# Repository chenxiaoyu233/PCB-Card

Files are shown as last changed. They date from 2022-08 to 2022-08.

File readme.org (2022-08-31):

I always want to build some customized devices for myself, in which I have to implement both the hardware and the software.
I am quite familiar with softare development but only with little experience for the hardware development.

To implement the hardware, the most important part seems to be the design of printed circuit board (PCB).
And this project aims at gaining such kind of experience.

* The Card-V1 Project
** Startup
    First, I install the KiCad on my mac and I learn how to use it on bilibili.
    At the beginning, I randomly choose a MCU on [[https://list.szlcsc.com/][立创商城]], which is named as STM32L073RBT6 (about ¥50).
    Then I try to design the PCB according to this chip.

** Design the Schematic
    The most frustrated part in this step is to answer the question about how to driven the STM32L073RBT6 chip.
    That is, I want to know the "smallest" working requirement of this chip.
    Besides, I also need to figure out how to achieve these requirements on the PCB.
    Luckly, after a very long time, I find an article about how to achieve this ([[./doc/an4467-getting-started-with-stm32l0xx-hardware-development-stmicroelectronics.pdf][STM32L0xx-Hardware]]).

    Another question is to write my program into the chip.
    I find out that STM32L073RBT6 support USB DFU protocol in [[./doc/STM32-BOOT.pdf][STM32-BOOT]] (section 37.1).
    And I plan to download my program by a USB type-C port.
    Now, the question is, how to connect the USB prot to STM32L073RBT6 ?
    I find the answer in [[./doc/STM32-USB-Hardware.pdf][STM32-USB-Hardware]] (section 3.1.2).
    The USB port also handles the power supply.

    For future concern, I also add a circuit for a 1.54 inch e-paper screen ([[https://www.waveshare.net/shop/1.54inch-e-Paper-B.htm][e-paper-screen]]).
    The final result is like
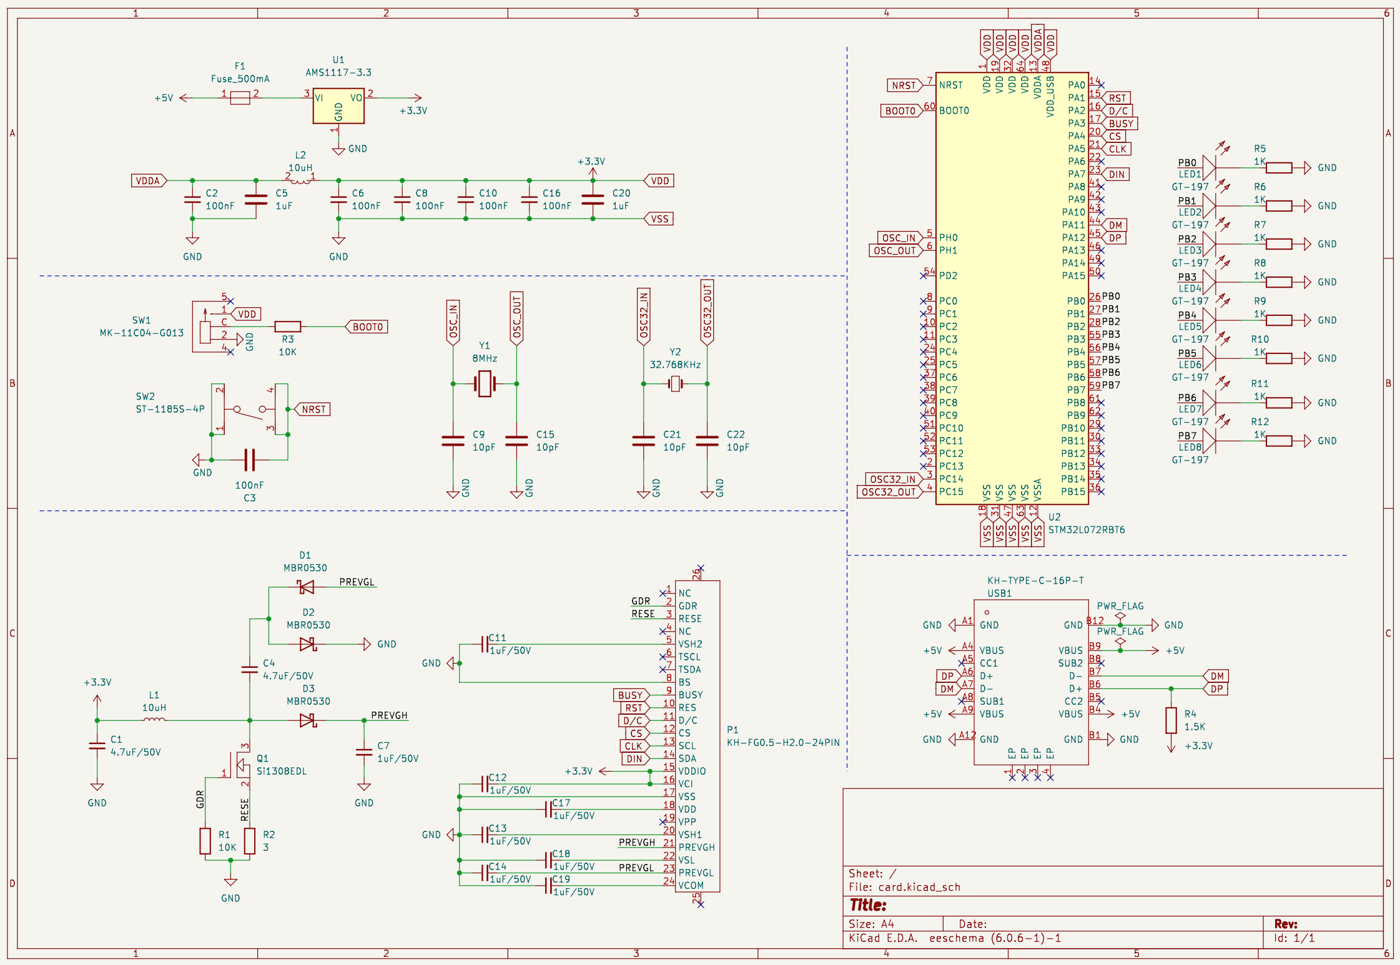
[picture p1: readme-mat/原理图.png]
    

** Design the PCB layout
    This step is quite simple because my pcb only runs at low speed.
    The final result is
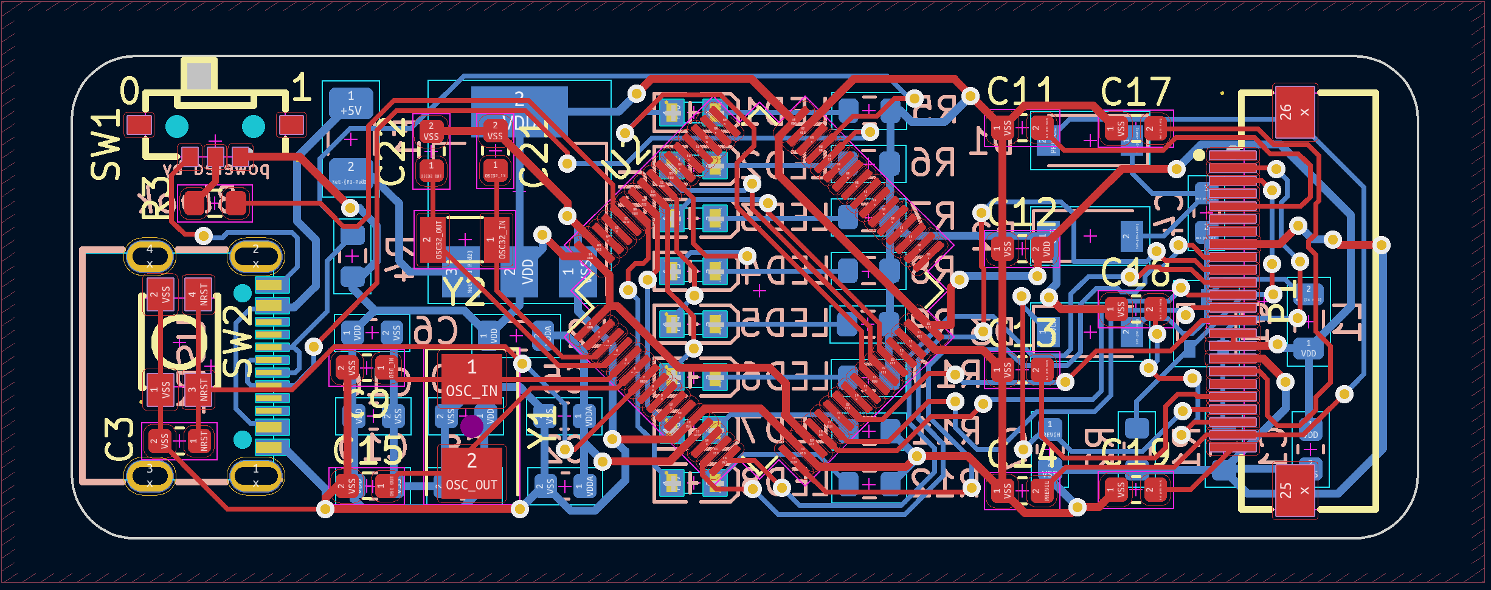
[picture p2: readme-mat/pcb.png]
    

** Order and Assemble
    I bought all the materials on [[https://list.szlcsc.com/][立创商城]] (about ¥60/suit) and order the PCB on [[https://www.jlc.com][嘉立创]] (about ¥30 for 5 PCBs).
    I assemble and weld these materials by using a heat gun.
    Here is the results.
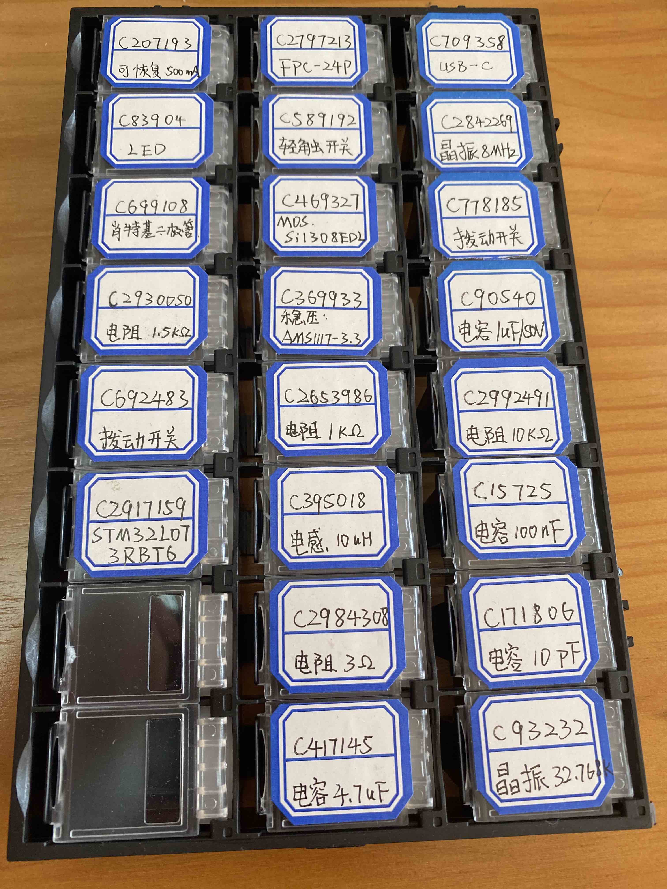
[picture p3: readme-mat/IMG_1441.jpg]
    
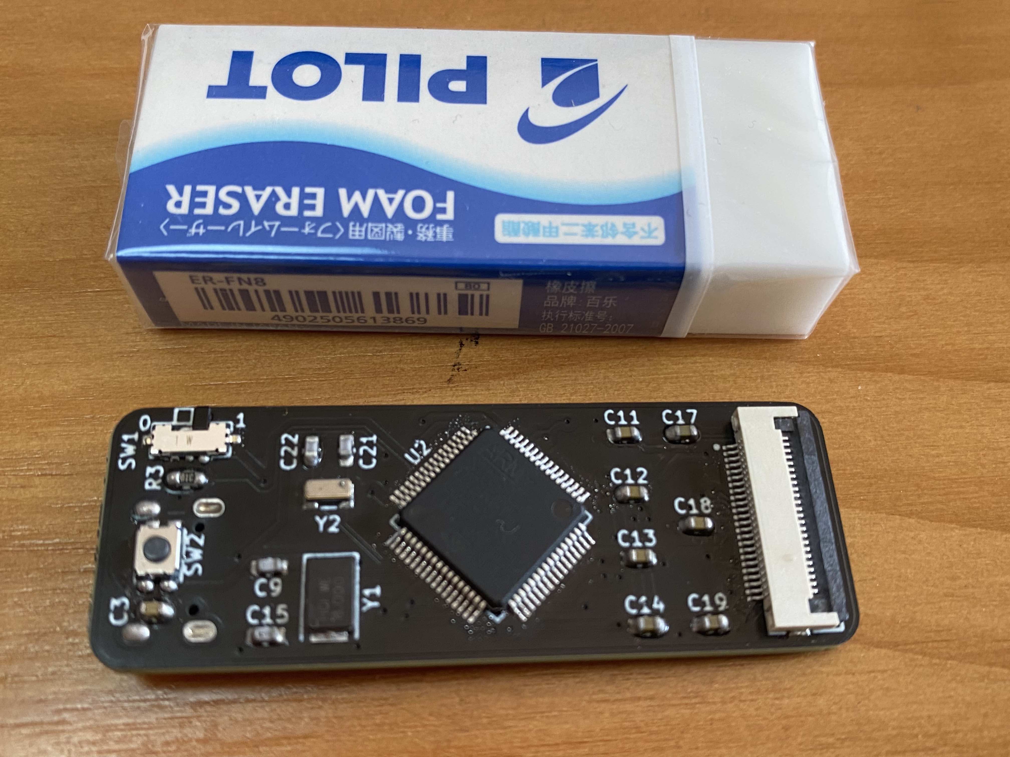
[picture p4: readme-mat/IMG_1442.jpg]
    
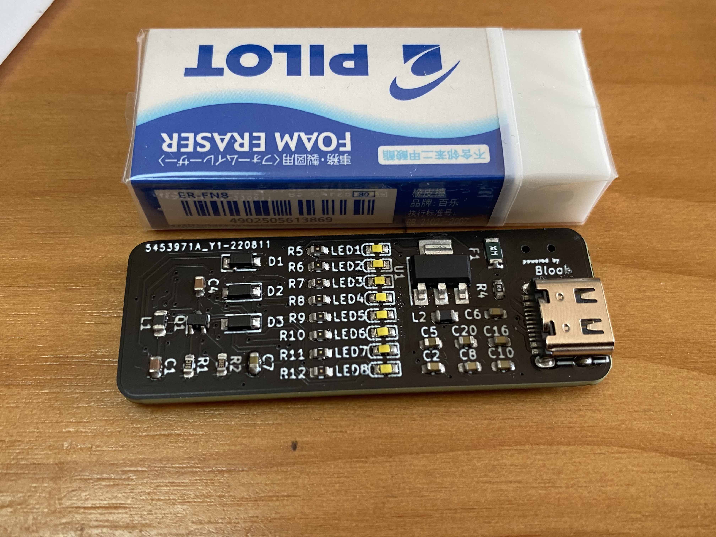
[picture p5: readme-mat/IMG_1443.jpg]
    

** Write Software and Blink the LED
    The document provided by ST ([[./doc/STM32L0x3-man.pdf][STM32L0x3-Manual]]) is very frustrated to read.
    It is so long and makes you confused about where to start.
    The crucial information for us is the boot mechanism of the chip.

    The chip has a RAM at =0x20002000= - =0x20004FFF= and a read-only flash memory at =0x08000000= - =0x0802FFFF=.
    When BOOT0 pin is set to 1, the chip runs a hard coded bootloader specified in [[./doc/STM32-BOOT.pdf][STM32-BOOT]] (section 37.1).
    This bootloader supports USB DFU protocol, which allows us to download our executables to the chip by the tool =dfu-util=.
    Our program need to be written in the beginning of the flash memory at =0x08000000=.

    When BOOT0 pin is set to 0, the chip initialized as follows:
    1. set the 32bit at =0x08000000= - =0x08000003= to register =SP=, which always point to the top of the stack (the stack grow towards 0).
       Typically, these 32bit should be set as =0x20004FFF= as the bottom of the RAM.
    2. set the 32bit at =0x08000004= - =0x08000007= to register =PC=, which is the program counter.

    This indicates us about how to initialize in our program.

    Now, since we connect the LEDs to the GPIOB ports of the chip, we only need to write 1 to GPIOB port to enlighten the LEDs.
    To do this, we need first enable the GPIOB ports at =RCC_IOPENR= register ([[./doc/STM32L0x3-man.pdf][STM32L0x3-Manual]], section 7.3.12).
    (I miss this step at first, and it tooks me a lot of time to figure out what happens).
    Then, we need to initialize the GPIOB ports by =GPIOB_MODER=, =GPIOB_OTYPER=, =GPIOB_OSPEEDR=, =GPIOB_PUPDR=, =GPIOB_ODR= registers ([[./doc/STM32L0x3-man.pdf][STM32L0x3-Manual]], section 9.4).
    These registers could be accessed using certain memory address.

    All the code could find at [[./code][code]].

** Debug
    Since I only use USB port to download the program, my PCB lacks debug infrastructure like SWD and ST-Link.
    So, I cannot do any on-board debugging, which makes it really hard to find out whats going wrong.

    Luckily, I could use qemu to simulate the STM32 and run my program on it first.
    Though the model is not exactly the same, it still helps me a lot.
    The material on [[./doc/STM32L0x3-man.pdf][STM32L0x3-Manual]] for the boot behavior is very ambiguous, you have to do some experiment to figure out what happens.

** Final Results
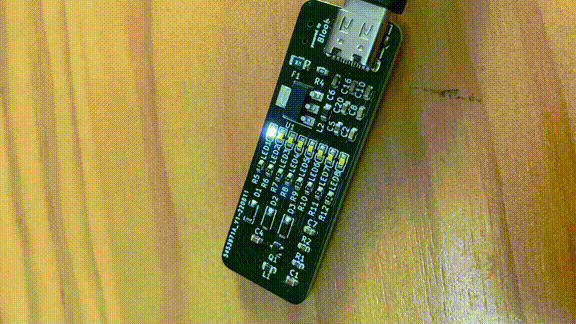
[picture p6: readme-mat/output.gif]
    
    
* The Card-V2 Project
  Based on the same hardware, the "card" could be use to drive an e-paper dispaly:  [[https://www.waveshare.net/shop/1.54inch-e-Paper.htm][wareshare 1.54inch e-paper]].
  During the development, I find that I use the wrong type of FPC connector, the original one is replaced by [[https://item.szlcsc.com/3194063.html][0425-A-A04-002 (C2911807)]].
  Moreover, the welding is really difficult and it tooks me tons of time to debug.

** Final Results
    Most code is generated by a tool called =STM32CubeMX=.
    The code is placed in [[./USBLib]] and could be build using =make=.
    Before using =make=, one should find an image of 200x200 and run =image-bin.py= in the folder =EPD= to convert it into a c header.

    The result is like:
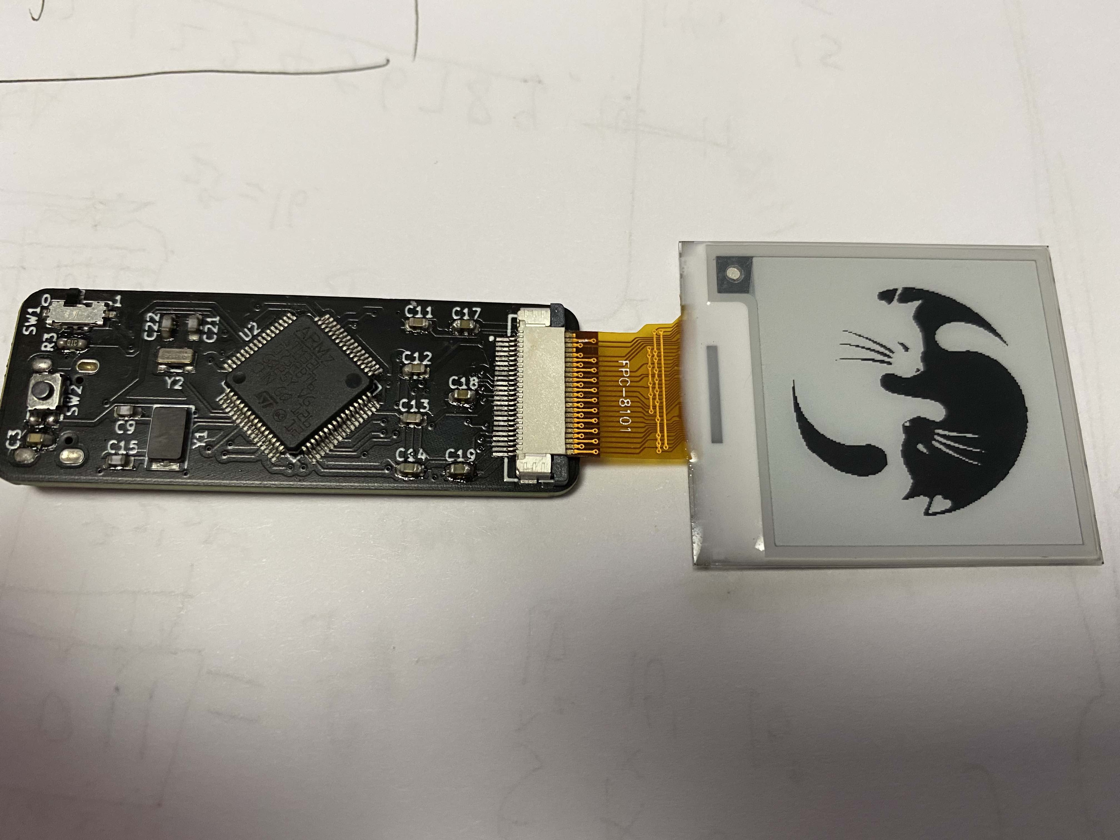
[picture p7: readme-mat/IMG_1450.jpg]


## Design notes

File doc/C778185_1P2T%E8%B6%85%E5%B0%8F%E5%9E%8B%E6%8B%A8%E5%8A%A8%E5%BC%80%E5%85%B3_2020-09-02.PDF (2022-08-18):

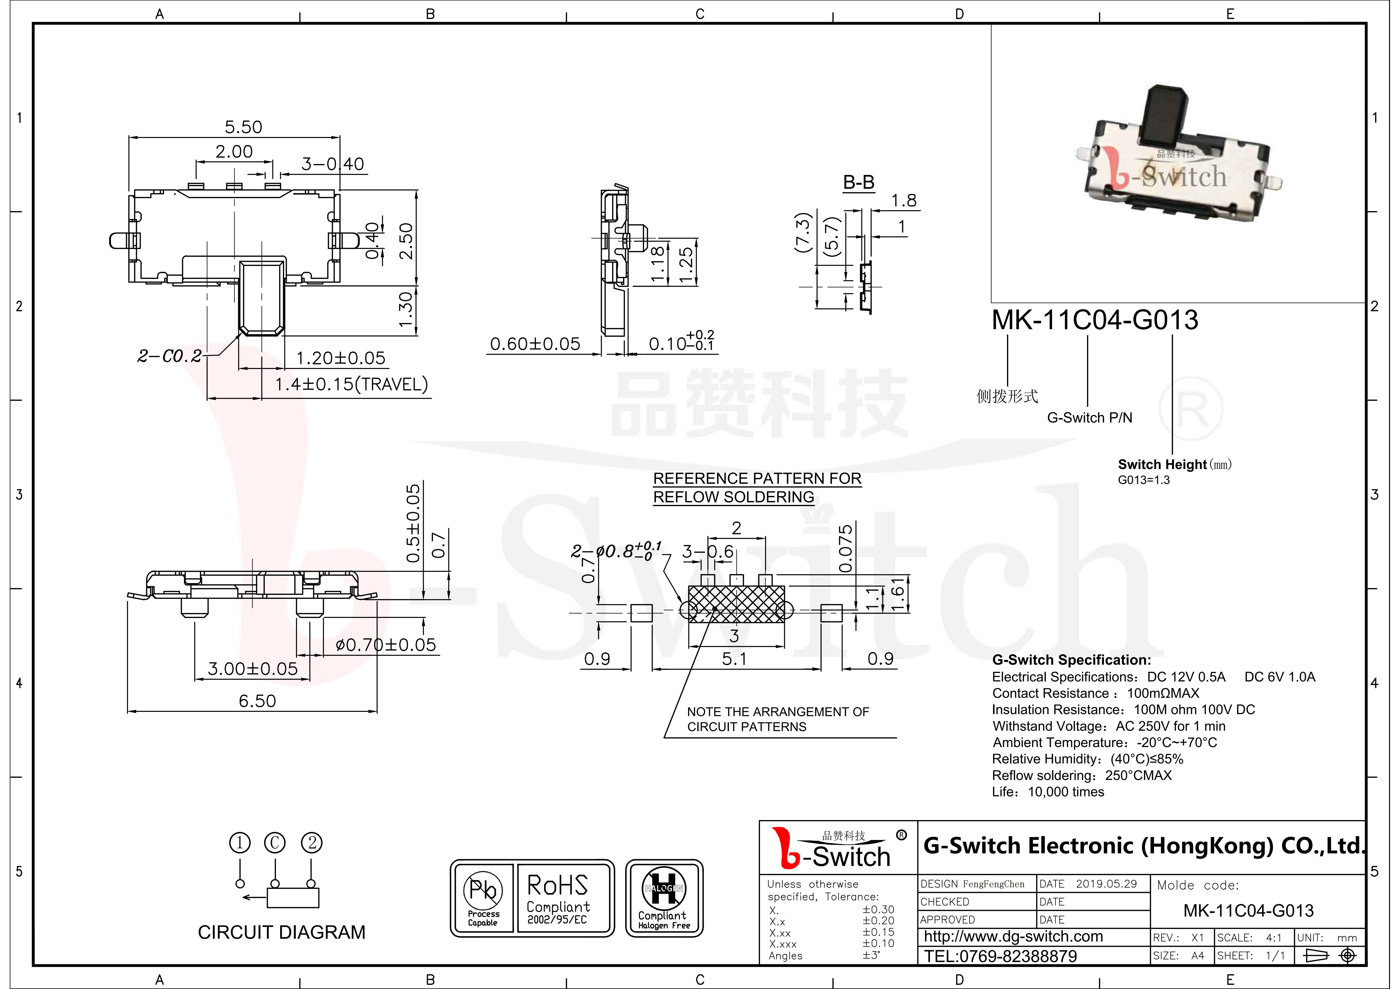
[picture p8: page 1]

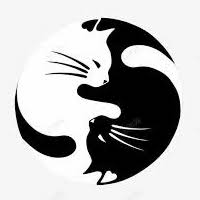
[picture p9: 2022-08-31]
USBLib/EPD/images.jpeg

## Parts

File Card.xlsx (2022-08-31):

Card 项目物料BOM清单
序号 | 名称 | 型号/规格 | 封装 | 用量 | 品牌 | 商品编号
1 | USB连接器 | KH-TYPE-C-16P-T | USB-C-SMD_KH-TYPE-C-16P | 1 | kinghelm | C709358
2 | 贴片无源晶振 | XC53G2-8.000-F12NJHP | SMD5032-2P | 1 | HCI | C2842269
3 | 1P2T超小型拨动开关 | MK-11C04-G013 | SW-SMD_MK-11C04-G013 | 1 | G-Switch | C778185
4 | 贴片电容 | 1uF ±10% 50V | 0603 | 8 | FH | C90540
5 | 贴片电阻 | 10kΩ ±0.1% | 0603 | 2 | Viking | C2992491
6 | 贴片电容 | 100nF ±10% 100V | 0603 | 6 | SAMSUNG | C15725
7 | 贴片电容 | 10pF ±0.5pF 50V | 0603 | 4 | TDK | C171806
8 | 贴片无源晶振 | 32.768KHz 12.5PF 20ppm | SMD3215-2P | 1 | KDS | C93232
9 | MCU | STM32L073RBT6 | LQFP-64 | 1 | ST | C915968
10 | FFC/FPC连接器 | 0425-A-A04-002 | FPC-SMD_KH-FG0.5-H2.0-24PIN | 1 | HDGC | C2911807
11 | 轻触开关 | ST-1185S-4P | SW-SMD_ST-1185S-4P | 1 | RISHENG | C589192
12 | 场效应管 | SI1308EDL-T1-GE3 | SOT-323 | 1 | VISHAY | C469327
13 | 线性稳压器 | AMS1117-3.3 | SOT-223 | 1 | KEXIN | C369933
14 | 贴片电容 | 1uF ±10% 50V | 0603 | 2 | FH | C90540
15 | 贴片电阻 | 1kΩ ±1% 250mW | 0603 | 8 | ROHM | C2653986
16 | 贴片电感 | 10uH ±10% | 0805 | 2 | FH | C395018
17 | 贴片电阻 | 3Ω ±0.1% 62.5mW | 0603 | 1 | Viking | C2984308
18 | 贴片电容 | 4.7uF ±10% | 0603 | 2 | muRata | C417145
19 | 可恢复保险丝 | 500mA | 1206 | 1 | Littelfuse | C207193
20 | 发光二极管 | GT-197 | 0603 | 8 | EVERLIGHT | C83904
21 | 肖特基二极管 | MBR0530 | SOD-123 | 3 | YANGJIE | C699108
22 | 贴片电阻 | 1.5kΩ ±1% 100mW | 0603 | 1 | FOJAN | C2930050
请将需要匹配的BOM放在第一个工作表即sheet1

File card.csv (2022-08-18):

ID | 指示符 | 软件包 | 数量 | 名称 | 供应商和参考
1 | USB1 | USB-C-SMD_KH-TYPE-C-16P | 1 | KH-TYPE-C-16P-T
2 | Y1 | Crystal_SMD_5032-2Pin_5.0x3.2mm | 1 | 8MHz
3 | SW1 | SW-SMD_MK-11C04-G013 | 1 | MK-11C04-G013
4 | C13,C11,C17,C19,C18,C14,C12,C7 | C_0603_1608Metric | 8 | 1uF/50V
5 | R3,R1 | R_0603_1608Metric | 2 | 10K
6 | C3,C6,C2,C10,C8,C16 | C_0603_1608Metric | 6 | 100nF
7 | C22,C15,C9,C21 | C_0603_1608Metric | 4 | 10pF
8 | Y2 | Crystal_SMD_3215-2Pin_3.2x1.5mm | 1 | 32.768KHz
9 | U2 | LQFP-64_10x10mm_P0.5mm | 1 | STM32L072RBT6
10 | P1 | FPC-SMD_KH-FG0.5-H2.0-24PIN | 1 | KH-FG0.5-H2.0-24PIN
11 | SW2 | SW-SMD_ST-1185S-4P | 1 | ST-1185S-4P
12 | Q1 | SOT-323_SC-70 | 1 | Si1308EDL
13 | U1 | SOT-223-3_TabPin2 | 1 | AMS1117-3.3
14 | C5,C20 | C_0603_1608Metric | 2 | 1uF
15 | R11,R5,R8,R10,R6,R9,R12,R7 | R_0603_1608Metric | 8 | 1K
16 | L1,L2 | L_0805_2012Metric | 2 | 10uH
17 | R2 | R_0603_1608Metric | 1 | 3
18 | C1,C4 | C_0603_1608Metric | 2 | 4.7uF/50V
19 | F1 | Fuse_1206_3216Metric | 1 | Fuse_500mA
20 | LED6,LED2,LED3,LED7,LED4,LED1,LED5,LED8 | LED0603-FD | 8 | GT-197
21 | D2,D1,D3 | D_SOD-123 | 3 | MBR0530
22 | R4 | R_0603_1608Metric | 1 | 1.5K

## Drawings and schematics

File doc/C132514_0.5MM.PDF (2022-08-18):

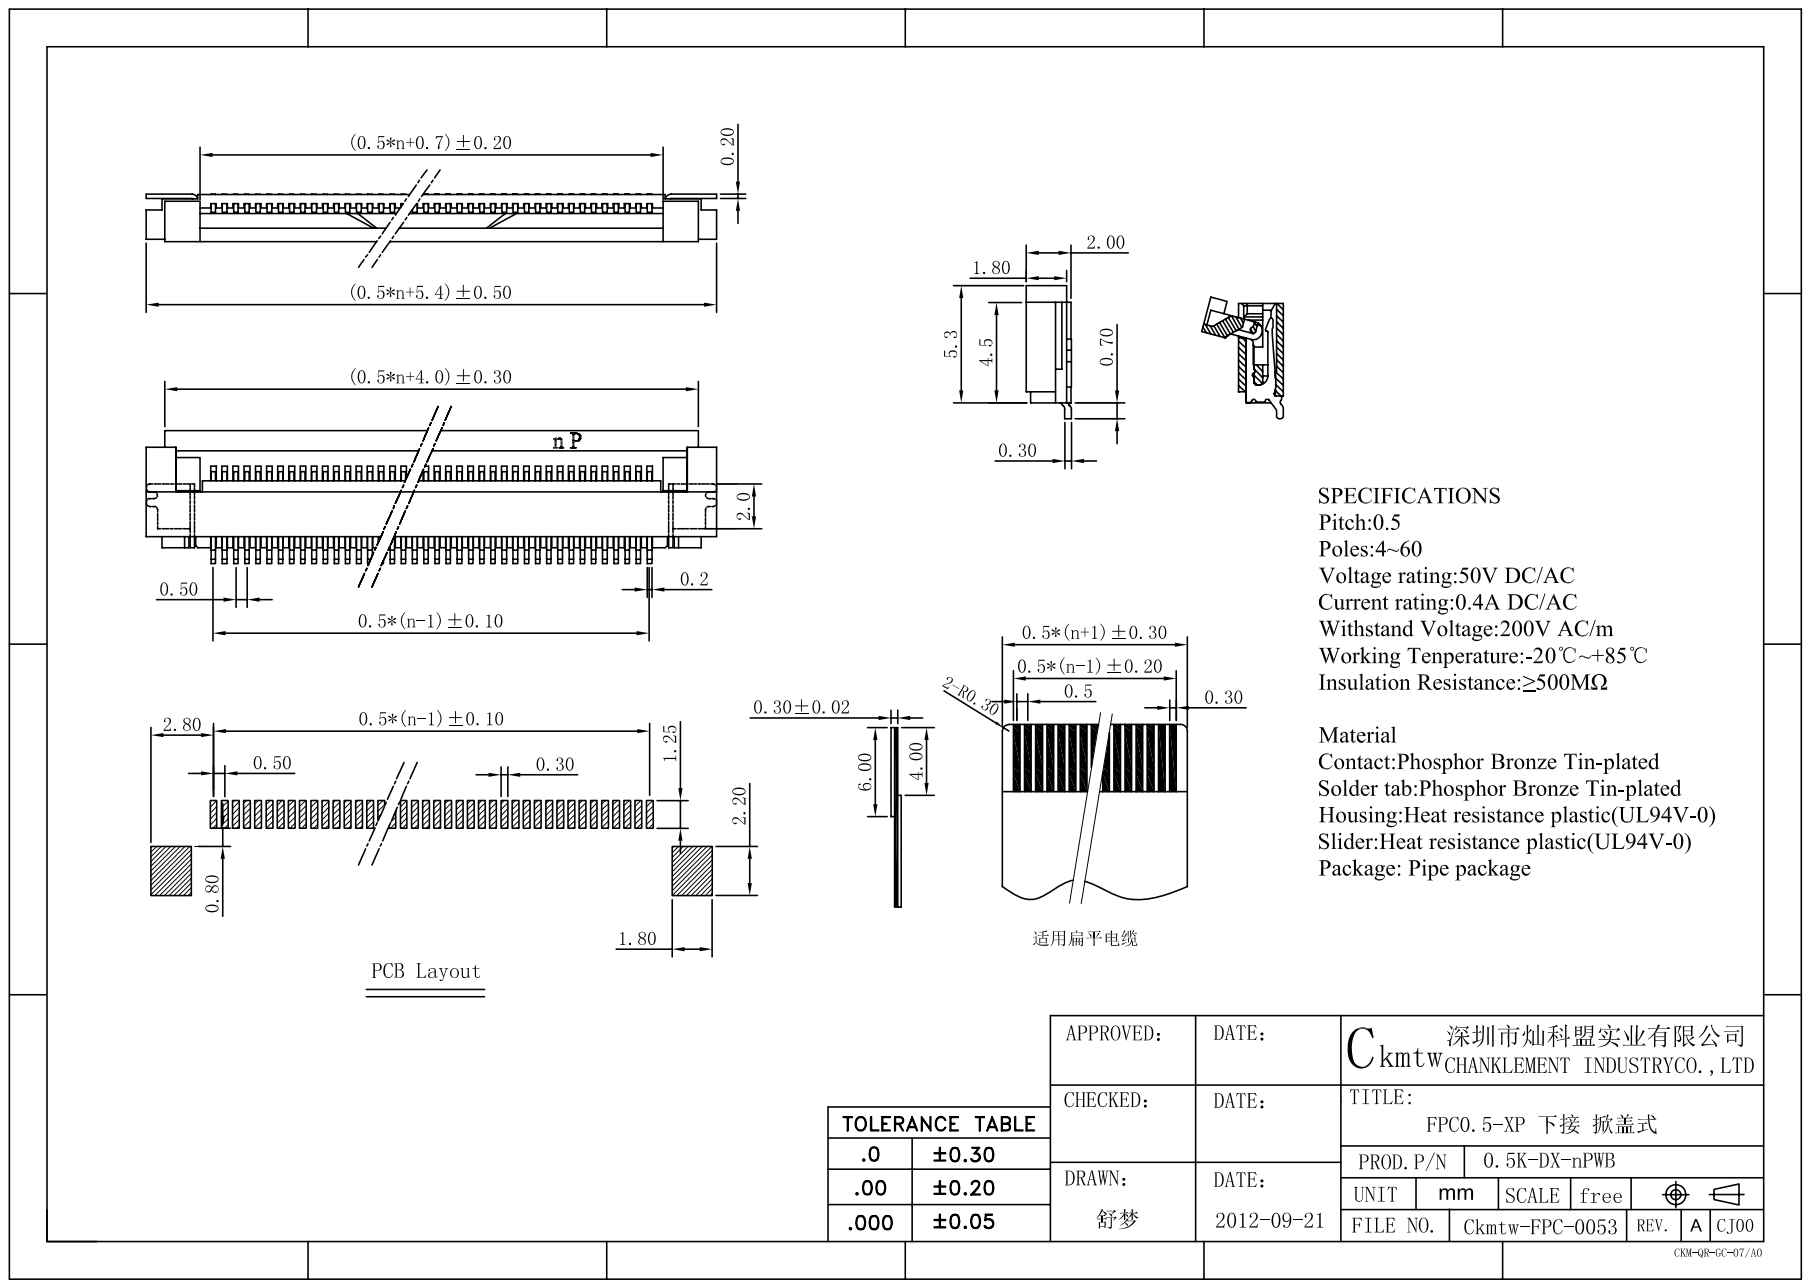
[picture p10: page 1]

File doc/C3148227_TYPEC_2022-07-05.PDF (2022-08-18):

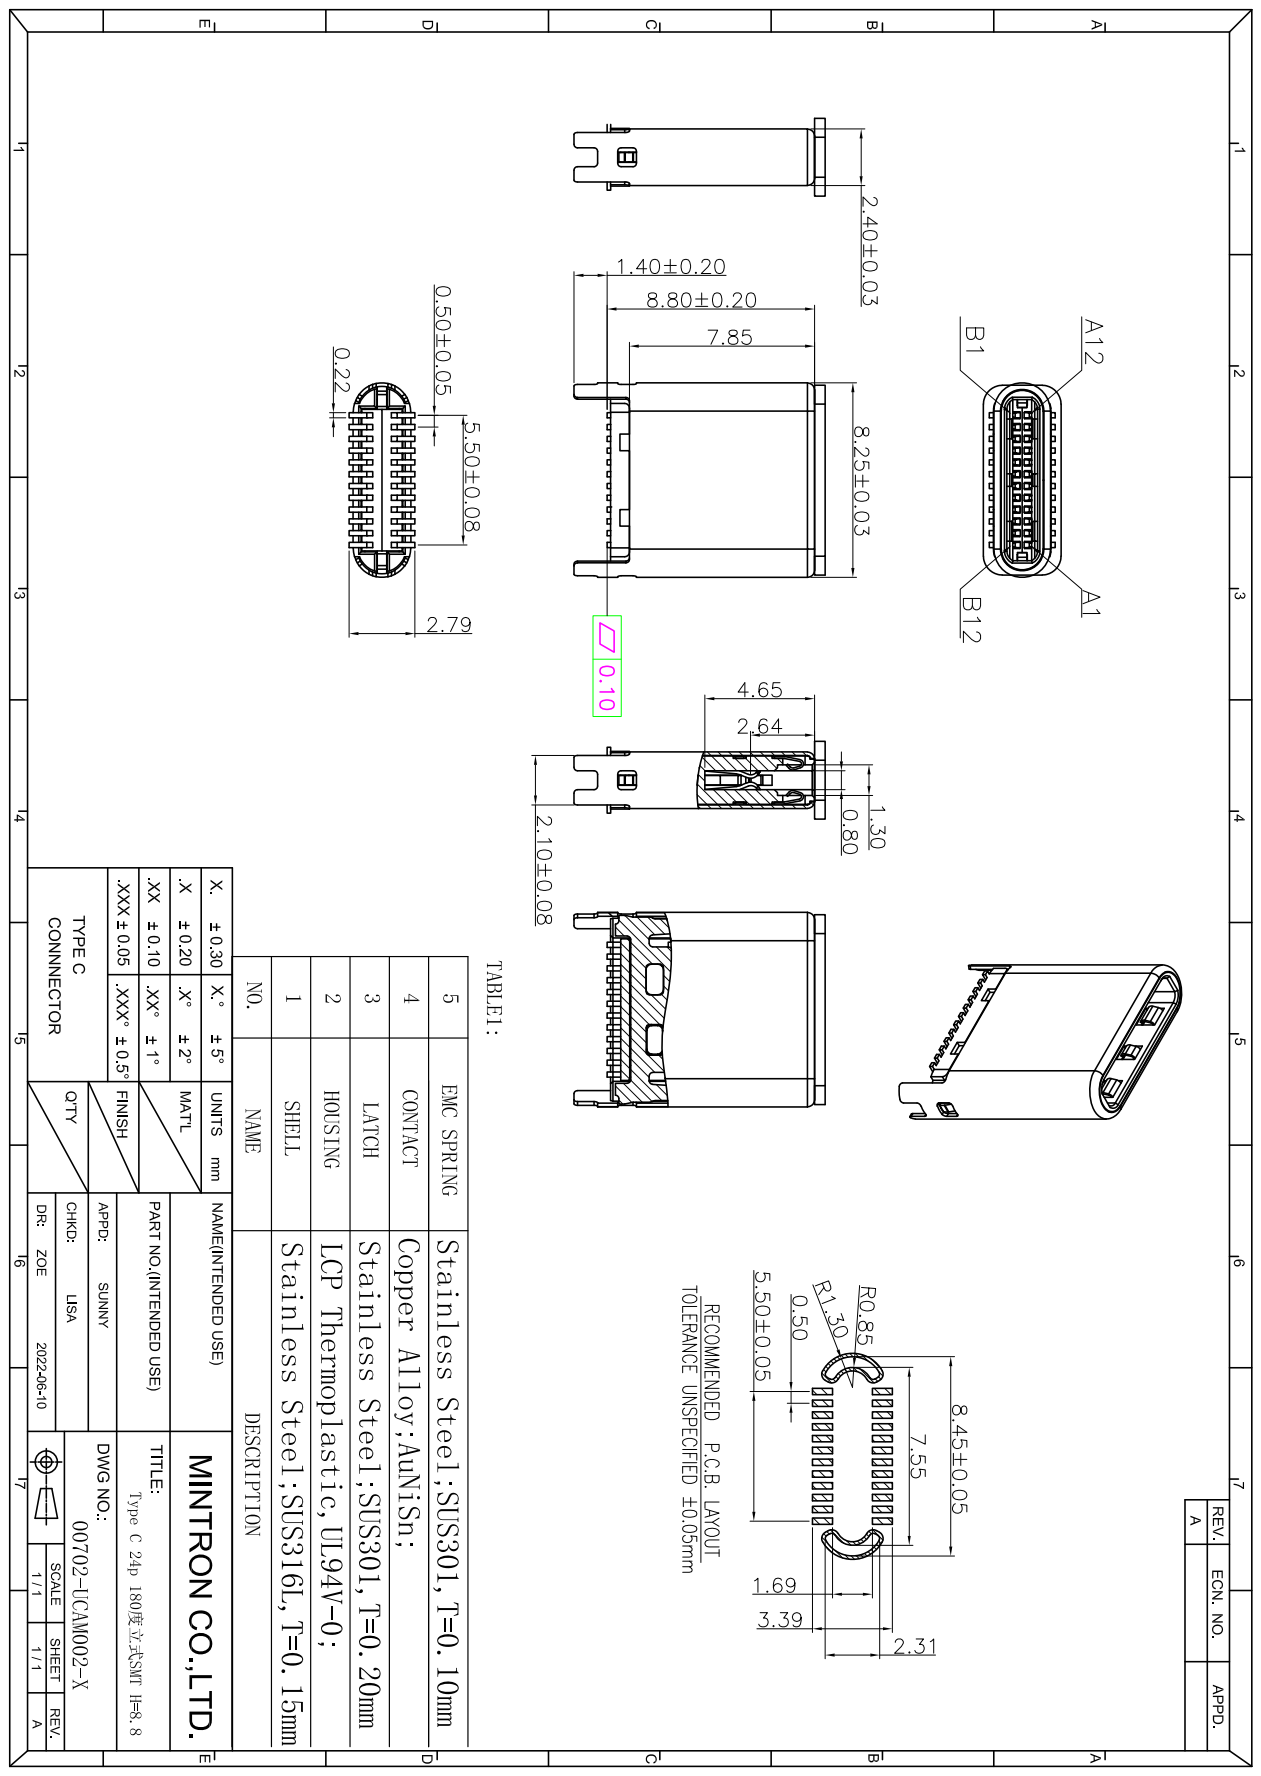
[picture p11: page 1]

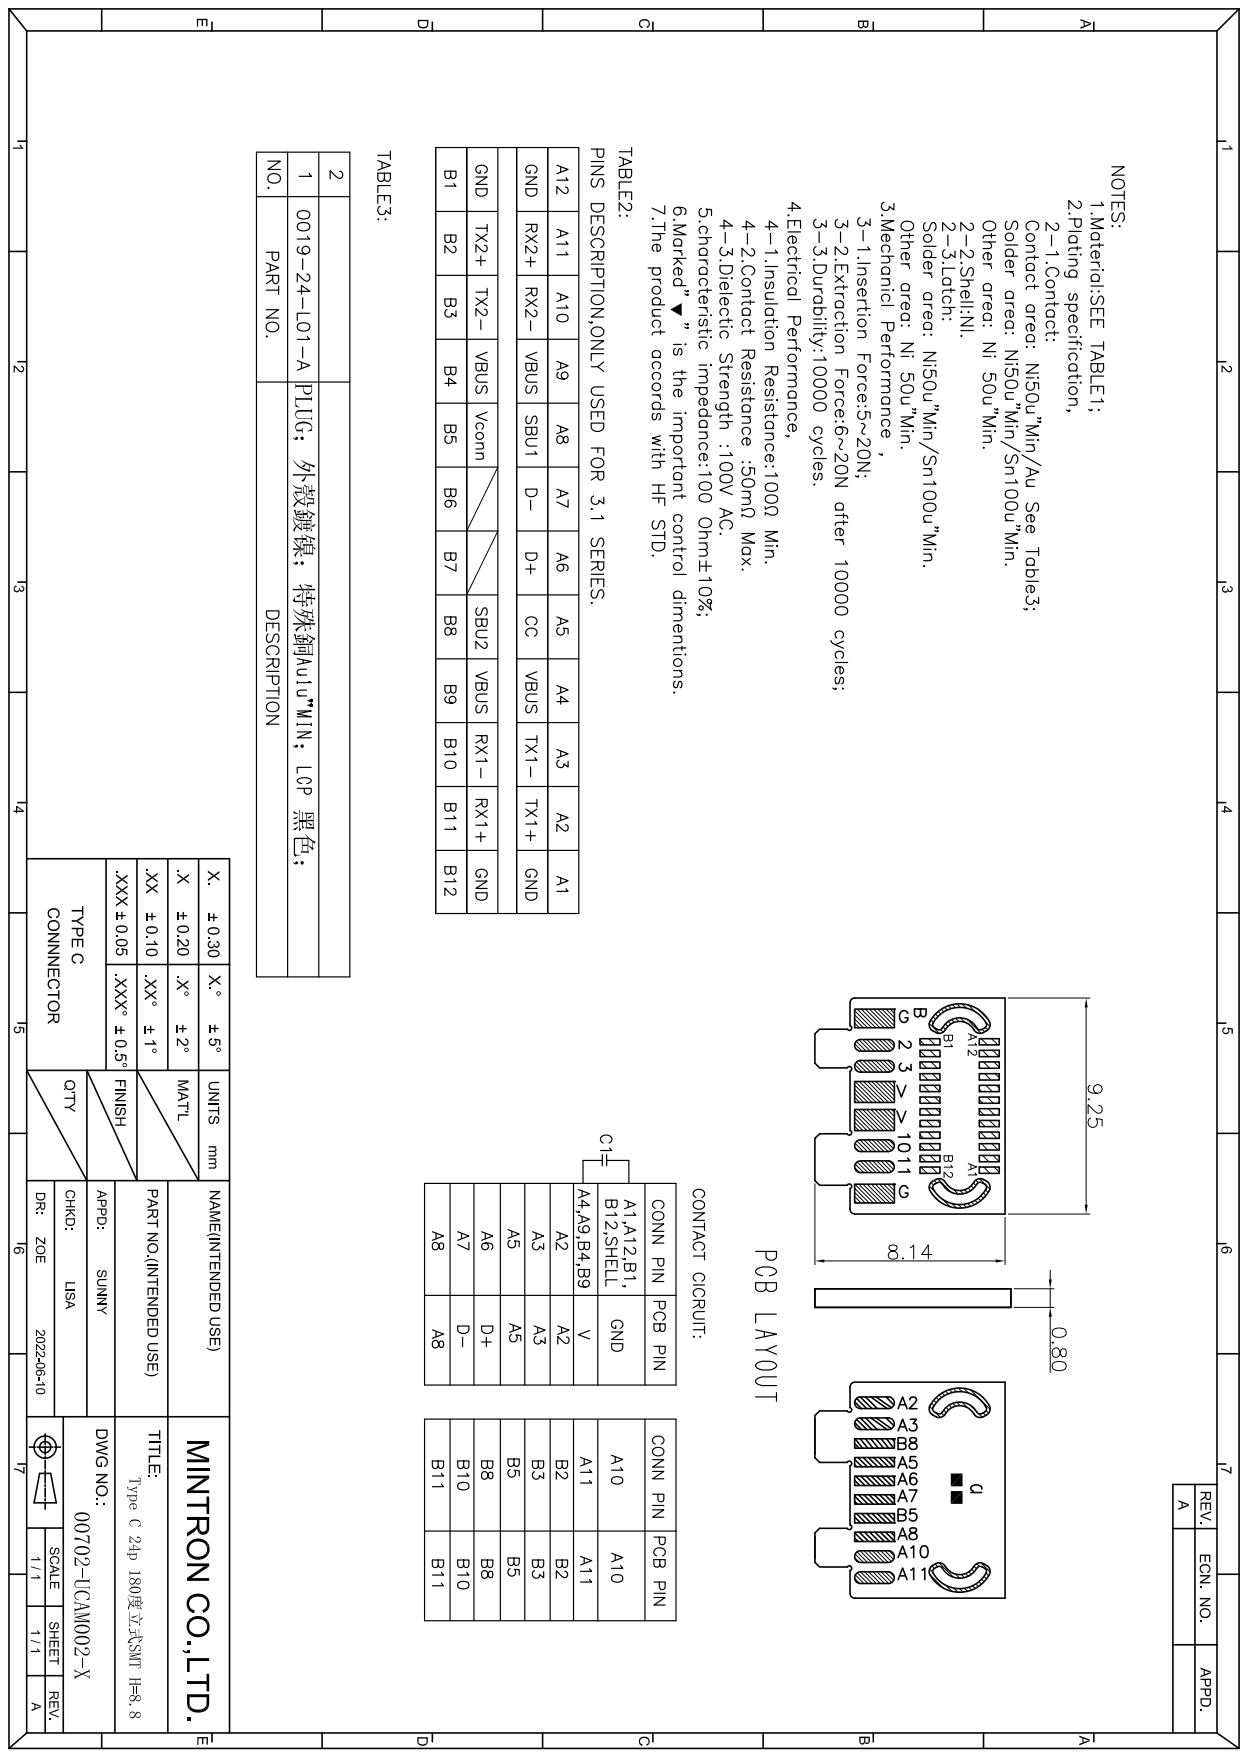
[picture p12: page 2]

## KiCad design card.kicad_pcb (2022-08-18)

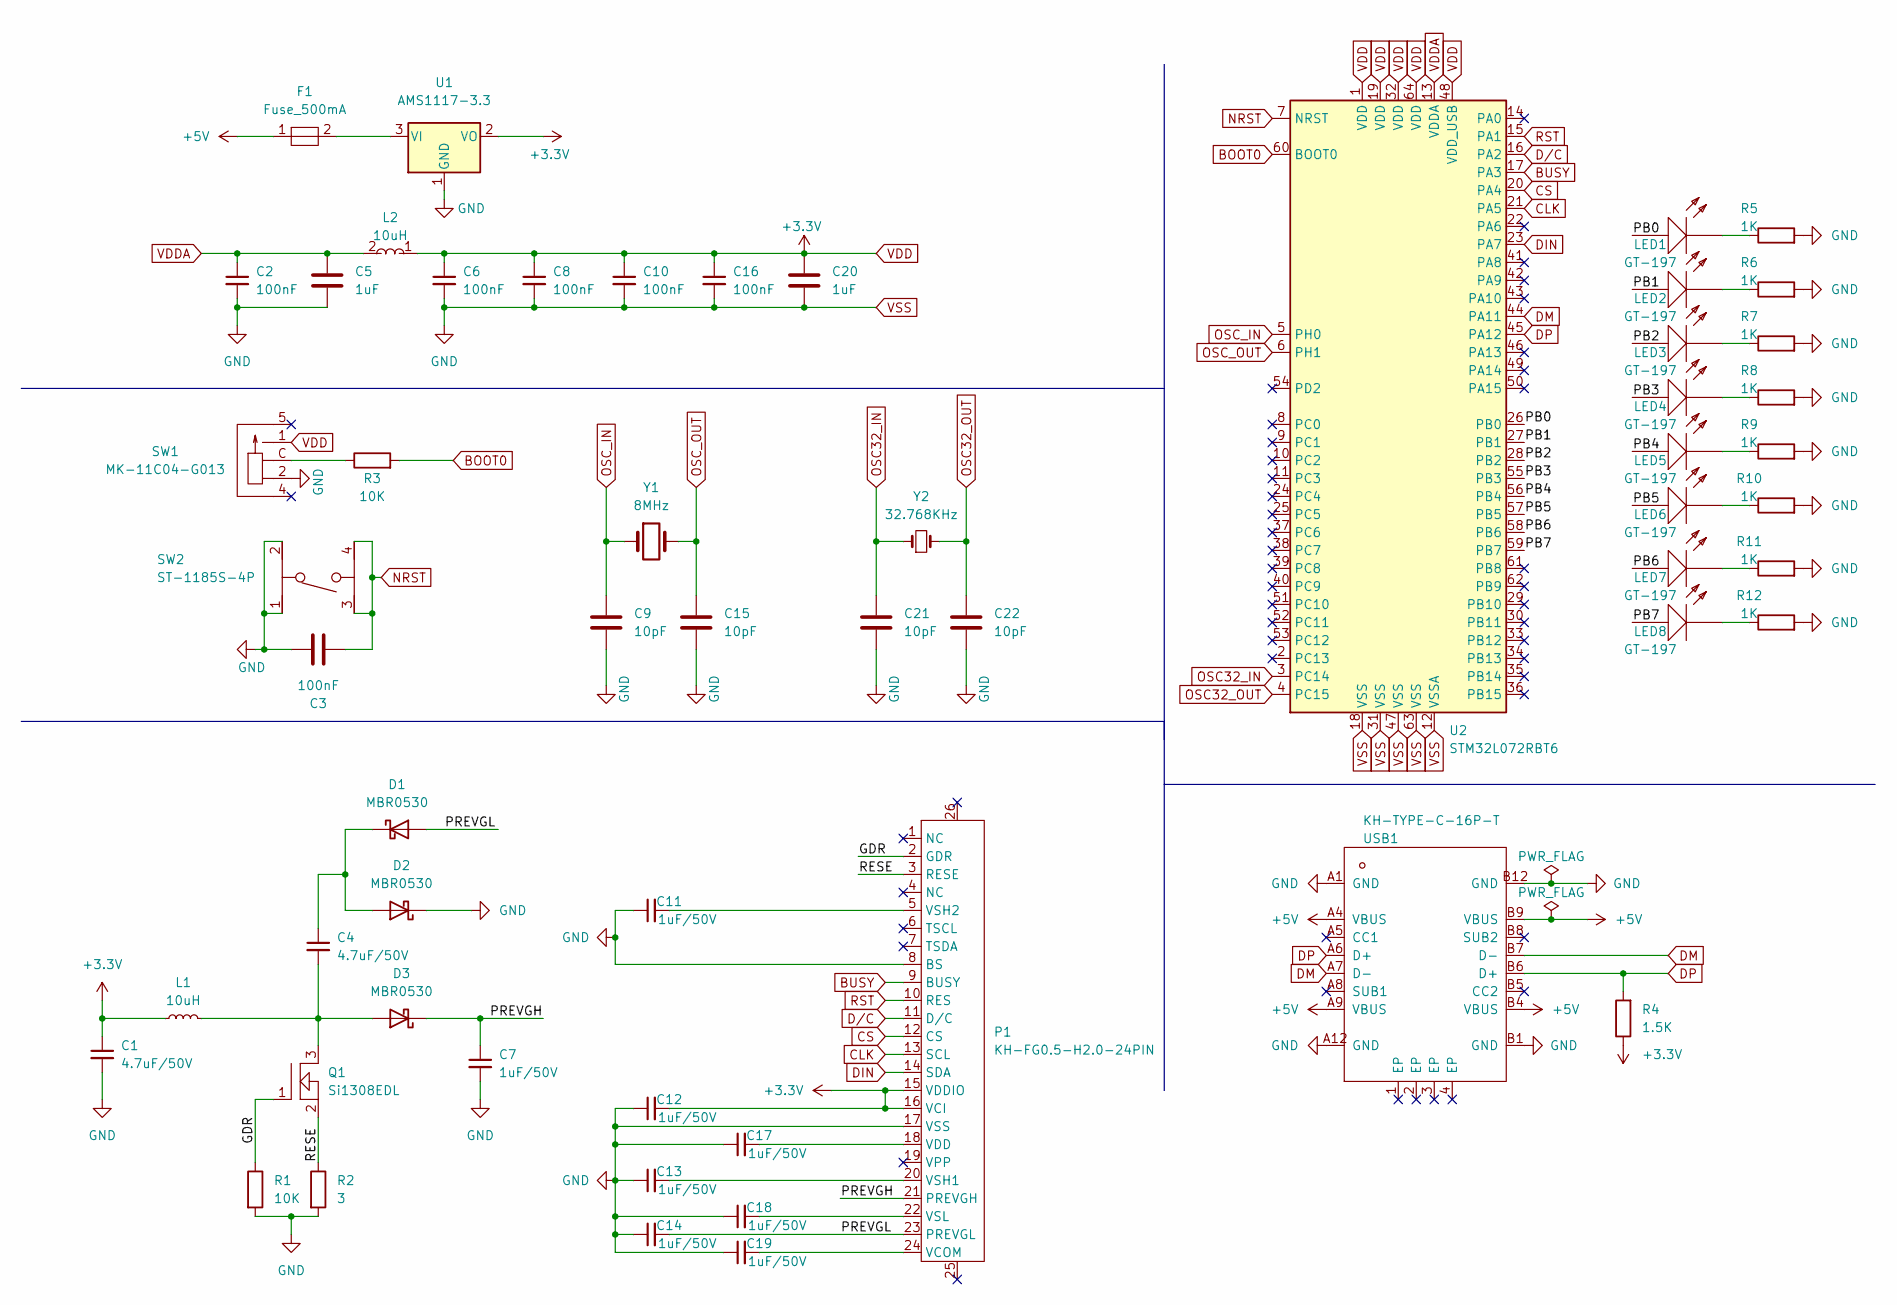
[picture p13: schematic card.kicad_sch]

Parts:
C1, C4: 4.7uF/50V; C_0603_1608Metric
C2, C3, C6, C8, C10, C16: 100nF; C_0603_1608Metric
C5, C20: 1uF; C_0603_1608Metric
C7, C11, C12, C13, C14, C17, C18, C19: 1uF/50V; C_0603_1608Metric
C9, C15, C21, C22: 10pF; C_0603_1608Metric
D1, D2, D3: MBR0530; D_SOD-123
F1: Fuse_500mA; Fuse_1206_3216Metric
L1, L2: 10uH; L_0805_2012Metric
LED1, LED2, LED3, LED4, LED5, LED6, LED7, LED8: GT-197; LED0603-FD
P1: KH-FG0.5-H2.0-24PIN; FPC-SMD_KH-FG0.5-H2.0-24PIN
Q1: Si1308EDL; SOT-323_SC-70
R1, R3: 10K; R_0603_1608Metric
R2: 3; R_0603_1608Metric
R4: 1.5K; R_0603_1608Metric
R5, R6, R7, R8, R9, R10, R11, R12: 1K; R_0603_1608Metric
SW1: MK-11C04-G013; SW-SMD_MK-11C04-G013
SW2: ST-1185S-4P; SW-SMD_ST-1185S-4P
U1: AMS1117-3.3; SOT-223-3_TabPin2
U2: STM32L072RBT6; LQFP-64_10x10mm_P0.5mm
USB1: KH-TYPE-C-16P-T; USB-C-SMD_KH-TYPE-C-16P
Y1: 8MHz; Crystal_SMD_5032-2Pin_5.0x3.2mm
Y2: 32.768KHz; Crystal_SMD_3215-2Pin_3.2x1.5mm

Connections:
+5V: F1.1, USB1.A4 (VBUS), USB1.A9 (VBUS), USB1.B4 (VBUS), USB1.B9 (VBUS)
/GDR: P1.2 (GDR), Q1.1, R1.1
/PB0: LED1.1 (A), U2.26 (PB0)
/PB1: LED2.1 (A), U2.27 (PB1)
/PB2: LED3.1 (A), U2.28 (PB2)
/PB3: LED4.1 (A), U2.55 (PB3)
/PB4: LED5.1 (A), U2.56 (PB4)
/PB5: LED6.1 (A), U2.57 (PB5)
/PB6: LED7.1 (A), U2.58 (PB6)
/PB7: LED8.1 (A), U2.59 (PB7)
/PREVGH: C7.1, D3.1 (K), P1.21 (PREVGH)
/PREVGL: C14.2, D1.2 (A), P1.23 (PREVGL)
/RESE: P1.3 (RESE), Q1.2, R2.1
BOOT0: R3.2, U2.60 (BOOT0)
BUSY: P1.9 (BUSY), U2.17 (PA3)
CLK: P1.13 (SCL), U2.21 (PA5)
CS: P1.12 (CS), U2.20 (PA4)
DIN: P1.14 (SDA), U2.23 (PA7)
DM: U2.44 (PA11), USB1.A7 (D-), USB1.B7 (D-)
DP: R4.2, U2.45 (PA12), USB1.A6 (D+), USB1.B6 (D+)
D/C: P1.11 (D/C), U2.16 (PA2)
NRST: C3.1, SW2.3, SW2.4, U2.7 (NRST)
unnamed: C4.1, D1.1 (K), D2.2 (A)
unnamed: C4.2, D3.2 (A), L1.2, Q1.3
unnamed: C11.2, P1.5 (VSH2)
unnamed: C13.2, P1.20 (VSH1)
unnamed: C17.2, P1.18 (VDD)
unnamed: C18.2, P1.22 (VSL)
unnamed: C19.2, P1.24 (VCOM)
unnamed: F1.2, U1.3 (VI)
unnamed: LED1.2 (K), R5.1
unnamed: LED2.2 (K), R6.1
unnamed: LED3.2 (K), R7.1
unnamed: LED4.2 (K), R8.1
unnamed: LED5.2 (K), R9.1
unnamed: LED6.2 (K), R10.1
unnamed: LED7.2 (K), R11.1
unnamed: LED8.2 (K), R12.1
unnamed: R3.1, SW1.C
OSC32_IN: C21.1, U2.3 (PC14), Y2.1
OSC32_OUT: C22.1, U2.4 (PC15), Y2.2
OSC_IN: C9.1, U2.5 (PH0), Y1.1
OSC_OUT: C15.1, U2.6 (PH1), Y1.2
RST: P1.10 (RES), U2.15 (PA1)
VDD: C1.1, C6.1, C8.1, C10.1, C12.2, C16.1, C20.1, L1.1, L2.1, P1.15 (VDDIO), P1.16 (VCI), R4.1, SW1.1, U1.2 (VO), U2.1 (VDD), U2.19 (VDD), U2.32 (VDD), U2.48 (VDD_USB), U2.64 (VDD)
VDDA: C2.1, C5.1, L2.2, U2.13 (VDDA)
VSS: C1.2, C2.2, C3.2, C5.2, C6.2, C7.2, C8.2, C9.2, C10.2, C11.1, C12.1, C13.1, C14.1, C15.2, C16.2, C17.1, C18.1, C19.1, C20.2, C21.2, C22.2, D2.1 (K), P1.8 (BS), P1.17 (VSS), R1.2, R2.2, R5.2, R6.2, R7.2, R8.2, R9.2, R10.2, R11.2, R12.2, SW1.2, SW2.1, SW2.2, U1.1 (GND), U2.12 (VSSA), U2.18 (VSS), U2.31 (VSS), U2.47 (VSS), U2.63 (VSS), USB1.A1 (GND), USB1.A12 (GND), USB1.B1 (GND), USB1.B12 (GND)

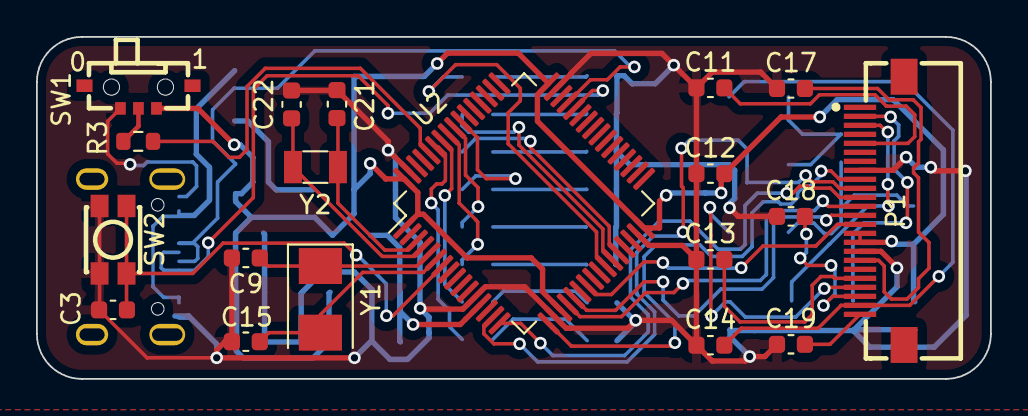
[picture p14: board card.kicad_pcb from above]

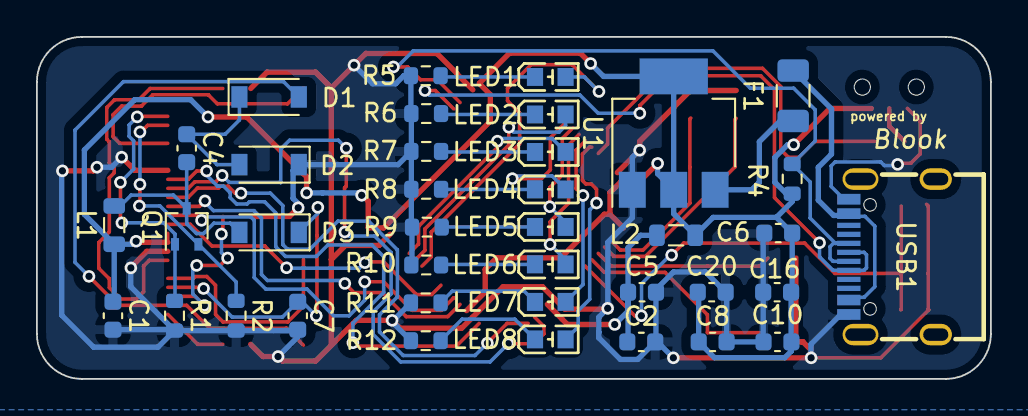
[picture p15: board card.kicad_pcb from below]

Board: 2 copper layers, 53.0 x 19.0 mm, 57 parts (38 on the bottom side), 47 nets.

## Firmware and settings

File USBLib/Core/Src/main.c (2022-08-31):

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
/* Includes ------------------------------------------------------------------*/
#include "main.h"

/* USER CODE BEGIN Includes */
//#include "EPD_1in54_V2.h"
//#include "GUI_Paint.h"
//#include "usbd_cdc_if.h"
/* USER CODE END Includes */


void SystemClock_Config(void);
static void MX_GPIO_Init(void);
/* USER CODE BEGIN 0 */
void db_LED_OFF(int i) {
    HAL_GPIO_WritePin(GPIOB, 1 << i, GPIO_PIN_RESET);
}
void db_LED_ON(int i) {
    HAL_GPIO_WritePin(GPIOB, 1 << i, GPIO_PIN_SET);
}

void db_LED(int i, int val){
    HAL_GPIO_WritePin(GPIOB, 1 << i, val);
}

/*
void db_PUT(const char* str) {
    uint16_t len = strlen(str);
    uint8_t* s = (uint8_t*) malloc(len);
    memcpy(s, str, len);
    CDC_Transmit_FS(s, len);
    free(s);
}
*/

void init_test();
void small_test();

/* USER CODE END 0 */

/**
  * @brief  The application entry point.
  * @retval int
  */
int main(void)
{
  /* MCU Configuration--------------------------------------------------------*/

  /* Reset of all peripherals, Initializes the Flash interface and the Systick. */
  HAL_Init();

  /* Configure the system clock */
  SystemClock_Config();

  /* Initialize all configured peripherals */
  MX_GPIO_Init();
  /* USER CODE BEGIN 2 */
  //SPI_test();
  init_test();
  //small_test();
  //test();
  /* USER CODE END 2 */

  /* Infinite loop */
  /* USER CODE BEGIN WHILE */
  while (1)
  {
    /* USER CODE END WHILE */

    /* USER CODE BEGIN 3 */
  }
  /* USER CODE END 3 */
}

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


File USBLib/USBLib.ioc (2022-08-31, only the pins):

Mcu.UserName=STM32L073RBTx
PA1.Signal=GPIO_Output
PA2.Signal=GPIO_Output
PA3.Signal=GPIO_Input
PA4.Signal=GPIO_Output
PA5.Signal=GPIO_Output
PA7.Signal=GPIO_Output
PB0.Signal=GPIO_Output
PB1.Signal=GPIO_Output
PB2.Signal=GPIO_Output
PB3.Signal=GPIO_Output
PB4.Signal=GPIO_Output
PB5.Signal=GPIO_Output
PB6.Signal=GPIO_Output
PB7.Signal=GPIO_Output

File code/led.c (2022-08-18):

#include <stdint.h>

// registers for GPIOB
#define GPIOB_BASE 0x50000400
#define MODER   *(volatile uint32_t *)(GPIOB_BASE + 0x00)
#define OTYPER  *(volatile uint32_t *)(GPIOB_BASE + 0x04)
#define OSPEEDR *(volatile uint32_t *)(GPIOB_BASE + 0x08)
#define PUPDR   *(volatile uint32_t *)(GPIOB_BASE + 0x0C)
#define IDR     *(volatile uint32_t *)(GPIOB_BASE + 0x10)
#define ODR     *(volatile uint32_t *)(GPIOB_BASE + 0x14)
#define BSRR    *(volatile uint32_t *)(GPIOB_BASE + 0x18)
#define LCKR    *(volatile uint32_t *)(GPIOB_BASE + 0x1C)
#define AFRL    *(volatile uint32_t *)(GPIOB_BASE + 0x20)
#define AFRH    *(volatile uint32_t *)(GPIOB_BASE + 0x24)
#define BRR     *(volatile uint32_t *)(GPIOB_BASE + 0x28)

// GPIO clock enable register
#define RCC_BASE 0x40021000
#define IOPENR  *(volatile uint32_t *)(RCC_BASE + 0x2C)

int main() {
    // setting 
    IOPENR = 0x00000002;
    MODER  = 0x55555555;
    ODR    = 0x000000FF;
    while(1) {
        for (int i = 0; i < 8; i++) {
            ODR = 1 << i;
            for (int j = 0; j < 50000; j++) { }
        }
    }
}

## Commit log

2022-08-18 Release Card-V1
    driven on-chip led
    [Card.xlsx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]
2022-08-31 Card-V2
    add e-paper display support
    [Card.xlsx]

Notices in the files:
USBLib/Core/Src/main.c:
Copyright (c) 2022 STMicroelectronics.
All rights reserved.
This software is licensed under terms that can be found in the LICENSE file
